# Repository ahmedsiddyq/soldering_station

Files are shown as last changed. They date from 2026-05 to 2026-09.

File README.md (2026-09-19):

# Soldering Station
WhatsApp Image 2026-09-19 at 11 39 38 PM
WhatsApp Image 2026-09-19 at 11 39 35 PM

DIY electronic soldering station project containing the hardware design, firmware, simulation files, and mechanical/laser-cut CAD files.

## Project Overview

This repository contains multiple development versions of a temperature-controlled soldering station:

- **LCD / digital soldering station** — PIC-based controller with temperature sensing, set-temperature input, PWM heater control, PI/PID-style control, UART, I²C, and display support.
- **Analog version** — earlier/full analog control design and PCB.
- **CAD / laser-cut parts** — enclosure and mechanical parts used for the station.
- **Simulation files** — Proteus project files for development and testing.

## Repository Structure

```text
soldering_station/
├── Full_anlog_uc38/
│   ├── circut/        # KiCad PCB/schematic
│   └── layout/        # Proteus/simulation and related files
├── lcd_ST/
│   ├── circut/        # KiCad schematic and PCB
│   └── firmware/
│       └── st_16f15223_irsegmet.X/
│           ├── main.c
│           ├── adc.c / adc.h
│           ├── display.c / display.h
│           ├── i2c1.c / i2c1.h
│           ├── pid.c / pid.h
│           ├── pwm.c / pwm.h
│           ├── timer_1ms.c / timer_1ms.h
│           ├── uart.c / uart.h
│           └── pin_deffiine.h
└── laser_cut_cad/
    └── *.lbrn2       # LightBurn CAD files
```

## LCD Soldering Station Firmware

The current firmware is written in C for a Microchip PIC16F1-series MCU and is developed with **MPLAB X / XC8**.

### Main firmware features

- 32 MHz internal oscillator
- Temperature ADC measurement
- Set-temperature ADC input
- 50-sample moving average
- 200 ms temperature-control period
- PWM heater control
- PI/PID-style temperature control
- Integral anti-windup
- 1 ms timer scheduling
- UART at 9600 baud
- I²C interface
- Numeric display
- Automatic display of the set temperature after a significant setpoint change

The main control loop collects ADC temperature samples into a 50-element buffer and calculates the average before updating the heater duty cycle.

### Current control parameters

```c
#define AVG_SAMPLES       50
#define PID_PERIOD_MS     200

#define S  20
#define KI 1
#define KP 5
```

PWM duty is limited to:

```text
0 ... 1000
```

## Pin Assignment

The current firmware pin map is documented in `pin_deffiine.h`.

| MCU Pin | Function |
|---|---|
| RA5 | Temperature ADC |
| RA4 | Temperature-set ADC |
| RC5 | Current sensing |
| RC4 | Heater PWM gate |
| RC2 | I²C SCL |
| RC1 | I²C SDA |
| RC0 | UART TX |
| RA2 | UART RX |
| RA1 | ICSPDAT |
| RA0 | ICSPCLK |

> Verify the exact MCU part number against the schematic and datasheet before building. Some existing firmware comments/configuration reference different PIC16F1522x/15225 variants.

## Firmware Build

Open:

```text
lcd_ST/firmware/st_16f15223_irsegmet.X
```

Development environment:

- MPLAB X IDE
- XC8 compiler
- PIC16F1522x device support package
- PICkit/programmer compatible with the selected MCU

The project contains the MPLAB X `nbproject` configuration and source files.

## Hardware Design

### LCD version

Located under:

```text
lcd_ST/circut/lcd_soldring_staion/
```

Main files:

- `lcd_soldring_staion.kicad_sch`
- `lcd_soldring_staion.kicad_pcb`

### Analog version

Located under:

```text
Full_anlog_uc38/circut/solder_staion/
```

Main files:

- `solder_staion.kicad_sch`
- `solder_staion.kicad_pcb`

## Simulation

Proteus simulation/development files are located in:

```text
Full_anlog_uc38/layout/
```

## Mechanical / Laser-Cut Design

Laser-cut enclosure/mechanical files are located in:

```text
laser_cut_cad/
```

The `.lbrn2` files can be opened with **LightBurn**.

## Development Status

This is an active DIY electronics project. Hardware, firmware, control parameters, and mechanical designs are still being developed and revised.

Current development includes:

- Temperature-control stability
- PI/PID tuning
- Temperature filtering
- Current sensing
- LCD/display interface
- PCB and enclosure development

## Safety

A soldering station contains a high-temperature heating element and may contain hazardous mains voltages depending on the power-supply design.

Use appropriate electrical isolation, fusing, grounding, thermal protection, over-temperature protection, enclosure, and strain relief.

Do not operate the heater unattended.

## License

No license has currently been specified for this repository. Unless a license is added, normal copyright restrictions apply to the repository contents.

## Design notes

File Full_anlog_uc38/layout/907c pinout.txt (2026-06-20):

1 heater
2 heater 
3 ground
4 +thermo
5 -thermo

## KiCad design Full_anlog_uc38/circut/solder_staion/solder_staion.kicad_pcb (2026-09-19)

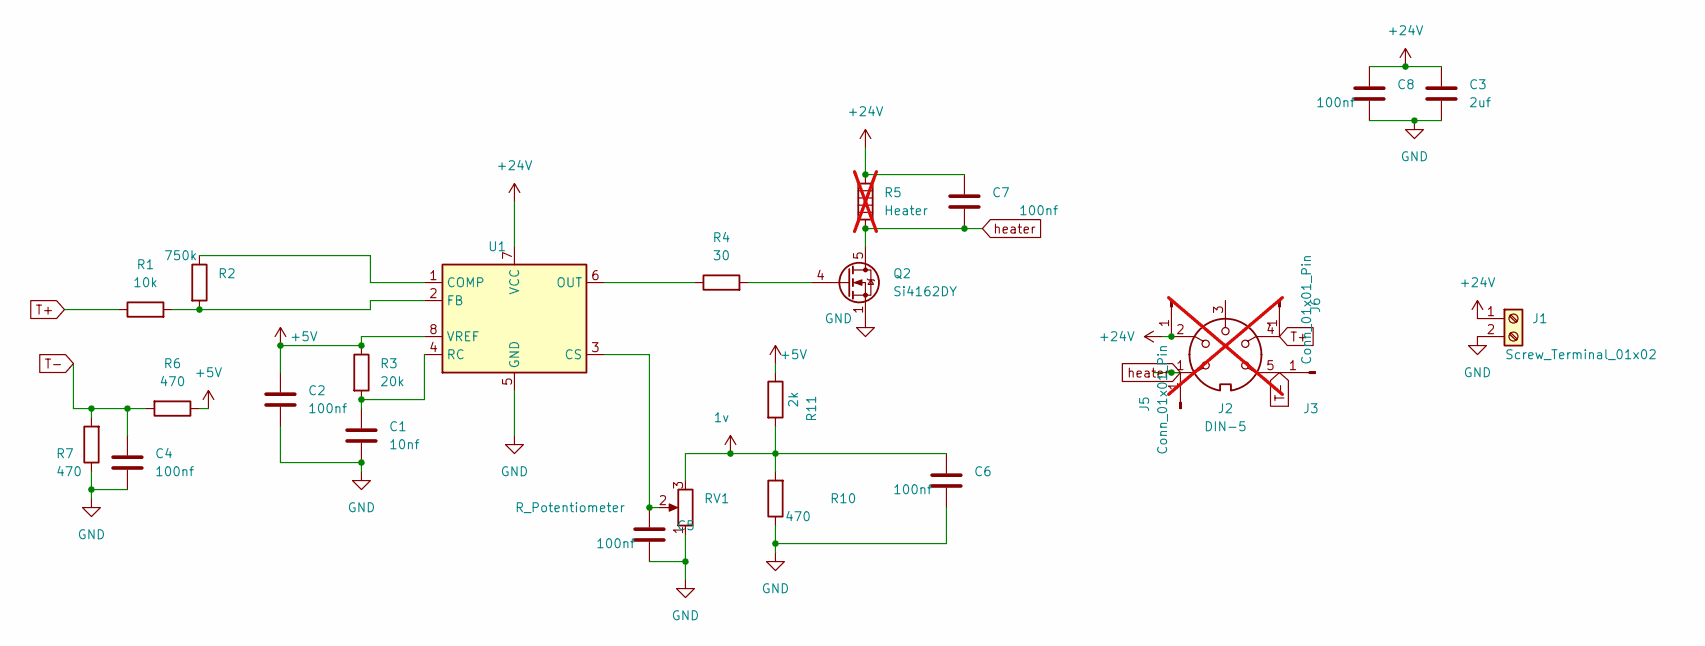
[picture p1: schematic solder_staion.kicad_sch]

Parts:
C1: 10nf; C_1206_3216Metric_Pad1.33x1.80mm_HandSolder
C2, C4, C5, C6, C7, C8: 100nf; C_1206_3216Metric_Pad1.33x1.80mm_HandSolder
C3: 2uf; C_1206_3216Metric_Pad1.33x1.80mm_HandSolder
J1: Screw_Terminal_01x02; TerminalBlock_MaiXu_MX126-5.0-02P_1x02_P5.00mm
J2: DIN-5; not fitted
J3: Conn_01x01_Pin; JST_XH_B1B-XH-AM_1x01_P2.50mm_Vertical
J4, J5, J6: Conn_01x01_Pin; PinHeader_1x01_P2.54mm_Horizontal
Q2: Si4162DY; SOIC-8_3.9x4.9mm_P1.27mm
R1: 10k; R_1206_3216Metric_Pad1.30x1.75mm_HandSolder
R2: 750k; R_1206_3216Metric_Pad1.30x1.75mm_HandSolder
R3: 20k; R_1206_3216Metric_Pad1.30x1.75mm_HandSolder
R4: 30; R_1206_3216Metric_Pad1.30x1.75mm_HandSolder
R5: Heater; not fitted
R6, R7, R10: 470; R_1206_3216Metric_Pad1.30x1.75mm_HandSolder
R11: 2k; R_1206_3216Metric_Pad1.30x1.75mm_HandSolder
RV1: R_Potentiometer; Potentiometer_ACP_CA9-H3,8_Horizontal
U1: UC3842_SOIC8; SOIC-8_3.9x4.9mm_P1.27mm

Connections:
1v: C6.1, R10.2, R11.2, RV1.3
+5V: C2.1, R3.1, R6.1, R11.1, U1.8 (VREF)
+24V: C3.1, C7.1, C8.1, J1.1, J2.2, J4.1, R5.1, U1.7 (VCC)
GND: C1.2, C2.2, C3.2, C4.2, C5.2, C6.2, C8.2, J1.2, Q2.1 (S), Q2.2 (S), Q2.3 (S), R7.1, R10.1, RV1.1, U1.5 (GND)
unnamed: Q2.4 (G), R4.2
unnamed: R2.1, U1.1 (COMP)
unnamed: C5.1, RV1.2, U1.3 (CS)
unnamed: R1.2, R2.2, U1.2 (FB)
unnamed: R4.1, U1.6 (OUT)
unnamed: C1.1, R3.2, U1.4 (RC)
T+: J2.4, J6.1, R1.1
T-: C4.1, J2.5, J3.1, R6.2, R7.2
heater: C7.2, J2.1, J5.1, Q2.5 (D), Q2.6 (D), Q2.7 (D), Q2.8 (D), R5.2

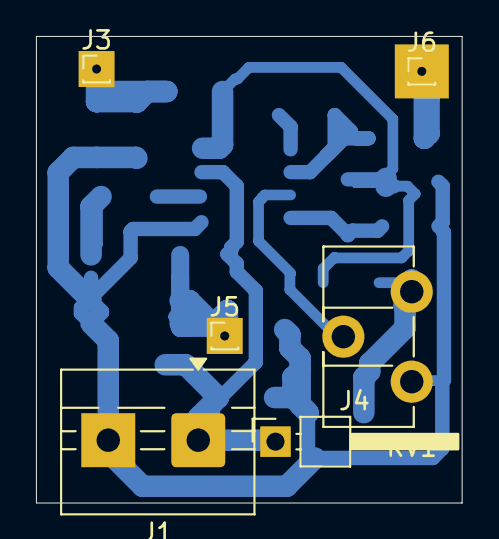
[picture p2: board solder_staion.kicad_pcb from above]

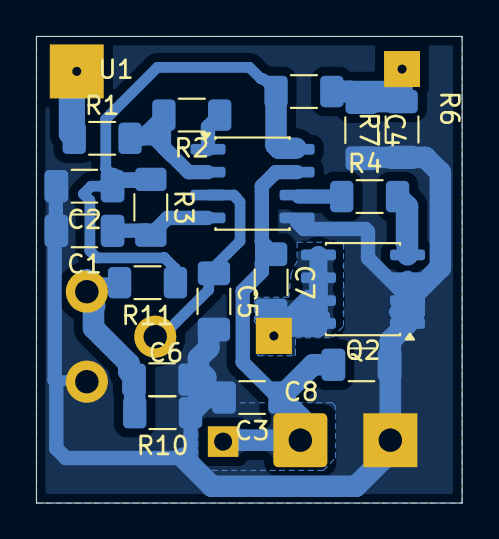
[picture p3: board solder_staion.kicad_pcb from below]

Board: 2 copper layers, 23.6 x 25.9 mm, 24 parts (18 on the bottom side), 13 nets.

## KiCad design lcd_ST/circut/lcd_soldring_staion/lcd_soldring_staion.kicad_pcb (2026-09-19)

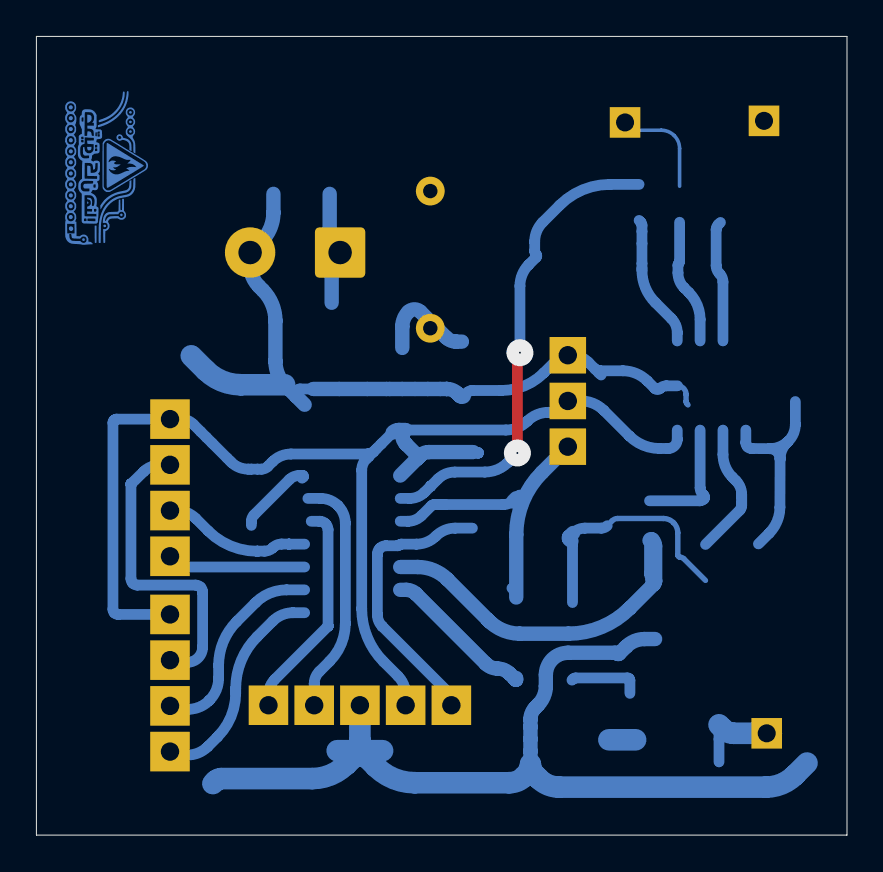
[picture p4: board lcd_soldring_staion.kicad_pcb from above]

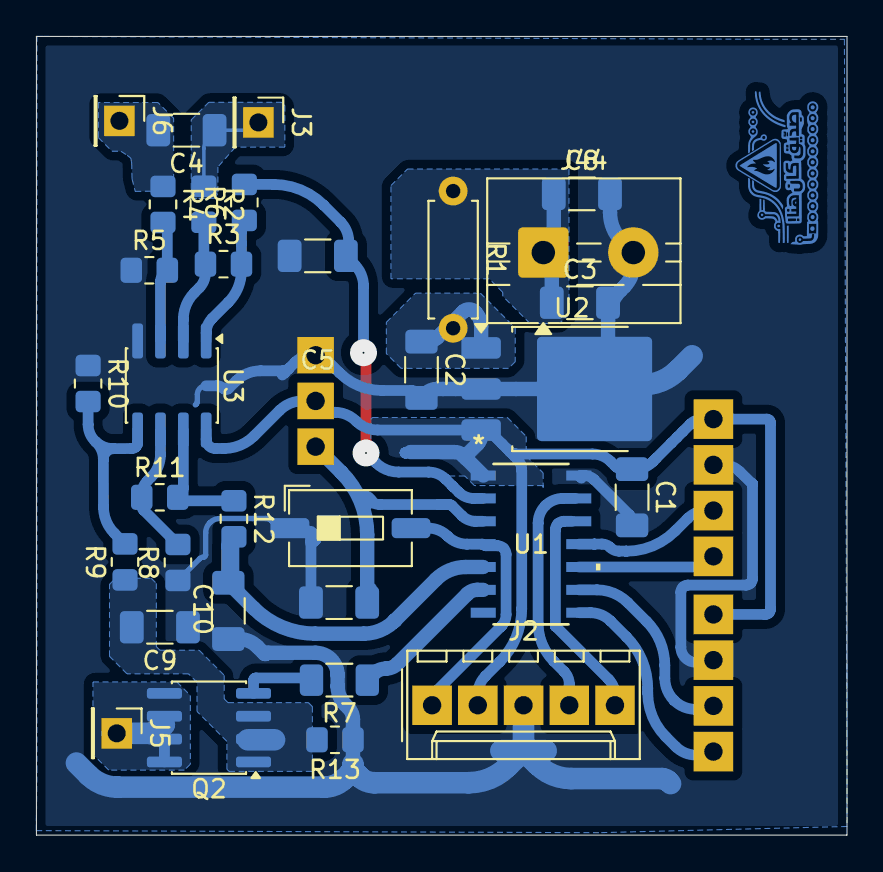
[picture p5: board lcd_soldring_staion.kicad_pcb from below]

Board: 2 copper layers, 45.0 x 44.4 mm, 35 parts (33 on the bottom side), 26 nets.

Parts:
C1: C; C_1206_3216Metric_Pad1.33x1.80mm_HandSolder
C2, C3: 2uf; C_1206_3216Metric_Pad1.33x1.80mm_HandSolder
C4, C5, C6, C8, C9, C10: 100nf; C_1206_3216Metric_Pad1.33x1.80mm_HandSolder
J2: Conn_01x05_Pin; Molex_KK-254_AE-6410-05A_1x05_P2.54mm_Vertical
J3, J5, J6: Conn_01x01_Pin; PinHeader_1x01_P2.54mm_Vertical
J7, J8: Conn_01x04_Pin; 01x04_fat_pins
J10: Conn_01x03_Pin; FanPinHeader_1x03_P2.54mm_Vertical
J44: Screw_Terminal_01x02; TerminalBlock_MaiXu_MX126-5.0-02P_1x02_P5.00mm
Q2: Si4162DY; SOIC-8_3.9x4.9mm_P1.27mm
R1: 50; R_Axial_DIN0207_L6.3mm_D2.5mm_P7.62mm_Horizontal
R2, R4, R6, R8, R9, R12, R13: 1K; R_0805_2012Metric_Pad1.20x1.40mm_HandSolder
R3, R5, R10, R11: 120K; R_0805_2012Metric_Pad1.20x1.40mm_HandSolder
R7: 0.02; R_1206_3216Metric_Pad1.30x1.75mm_HandSolder
SW1: SW_Push; SW_DIP_SPSTx01_Slide_6.7x4.1mm_W6.73mm_P2.54mm_LowProfile_J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
U1: PIC16F15223T-I/SL; SOIC14_SL_MCH
U2: L7805; TO-252-3_TabPin2
U3: LM358; SOIC-8_3.9x4.9mm_P1.27mm

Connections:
+24V: C3.1, C8.1, J44.1, R1.1
A: J2.4, U1.13 (RA0/ICSPDAT)
B: J2.5, U1.12 (RA1/ICSPCLK)
ClC: C6.1, J10.1, U1.3 (RA4)
unnamed: Q2.4 (G), R7.2
unnamed: R3.2, R6.1, U3.1
unnamed: R11.2, R12.1, U3.7
unnamed: C2.1, R1.2, U2.1 (IN)
unnamed: R4.2, R5.2, U3.3 (+)
unnamed: R2.2, R3.1, U3.2 (-)
unnamed: R9.2, R10.2, U3.5 (+)
unnamed: R8.2, R11.1, U3.6 (-)
RX: J8.1, U1.8 (RC2)
T+: C4.2, J6.1, R4.1
T-: C4.1, J3.1, R2.1
TEMP: C5.1, R6.2, U1.2 (RA5)
TX: J8.2, U1.9 (RC1)
VCC: C1.1, J2.2, J7.1, J8.4, J10.2, U1.1 (VDD), U2.3 (OUT), U3.8 (V+)
VPP: J2.1, SW1.2, U1.4 (*MCLR/VPP/RA3)
c+: C9.2, Q2.1 (S), Q2.2 (S), Q2.3 (S), R9.1, R13.2
c-: C1.2, C2.2, C3.2, C5.2, C6.2, C8.2, C9.1, C10.2, J2.3, J7.2, J8.3, J10.3, J44.2, R5.1, R8.1, R10.1, R13.1, SW1.1, U1.14 (VSS), U2.2 (GND), U3.4 (V-)
clk: J7.4, U1.10 (RC0)
current: C10.1, R12.2, U1.5 (RC5)
dat: J7.3, U1.11 (RA2)
heater: J5.1, Q2.5 (D), Q2.6 (D), Q2.7 (D), Q2.8 (D)
heater_gate: R7.1, U1.6 (RC4)

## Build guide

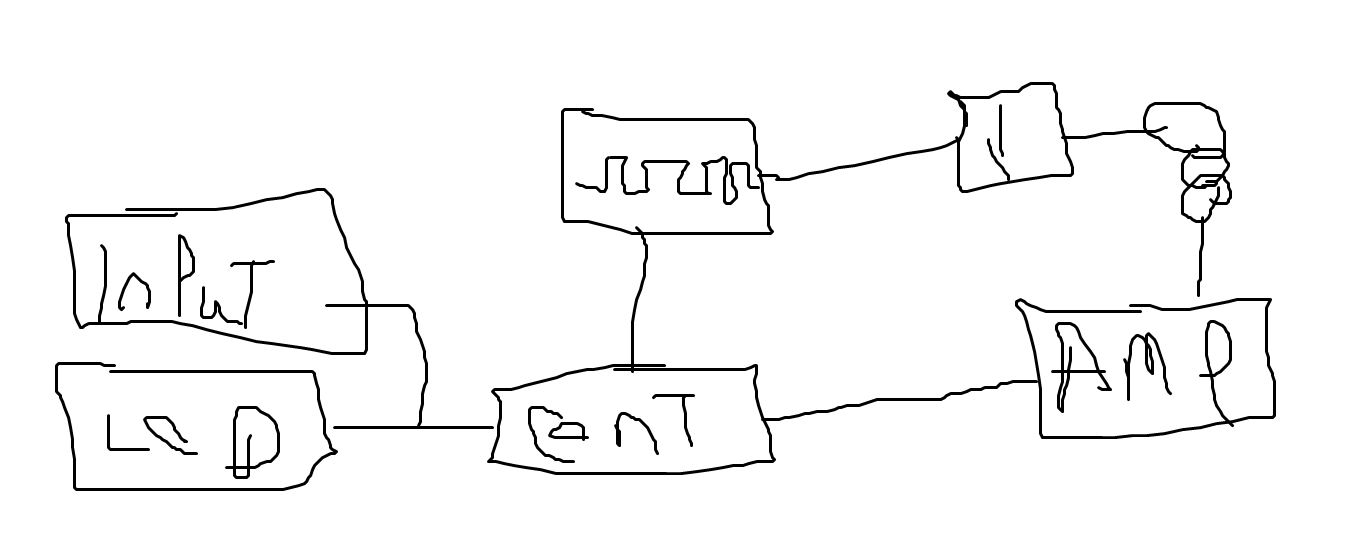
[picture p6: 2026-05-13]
Full_anlog_uc38/layout/Solder_iron_lcd.png

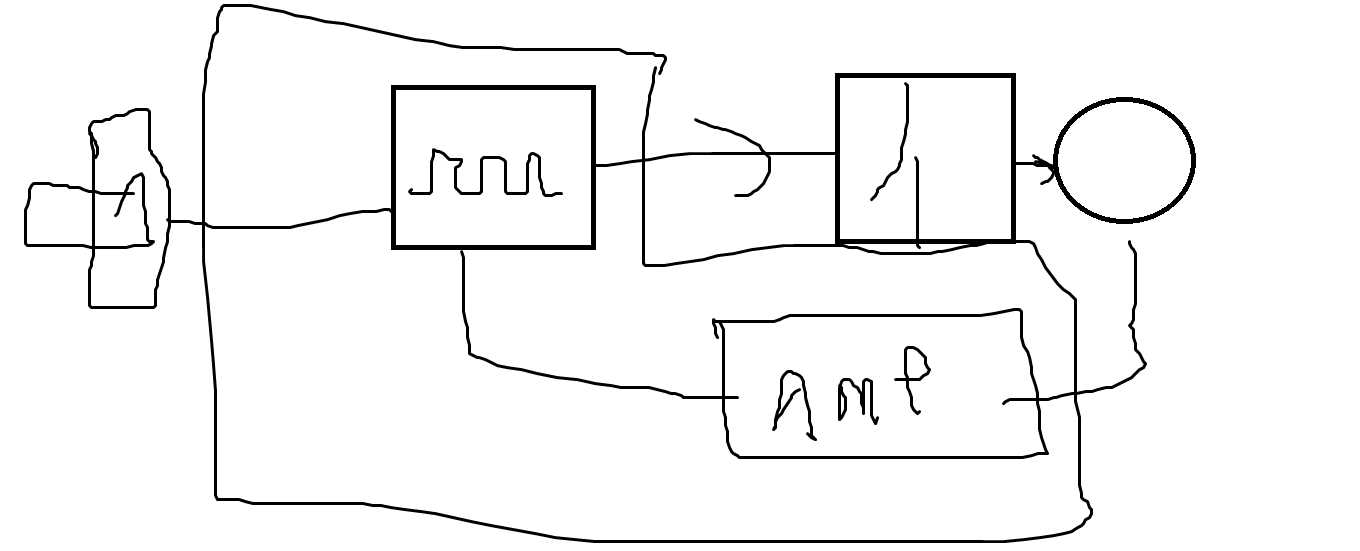
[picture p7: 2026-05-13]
Full_anlog_uc38/layout/solder_staion.png

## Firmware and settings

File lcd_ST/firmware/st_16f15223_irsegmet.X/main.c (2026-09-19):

#include <stdint.h>
#include "header.h"

#define _XTAL_FREQ 32000000UL

#define AVG_SAMPLES       50
#define PID_PERIOD_MS     200
#define SET_DISPLAY_MS    3000


/* ================= GLOBAL VARIABLES ================= */

uint16_t avr_t[AVG_SAMPLES] = {0};

volatile uint8_t tick_1ms = 0;

uint16_t tick_1s = 0;
uint16_t tick_pid = 0;

uint8_t pid_en = 0;
uint8_t SW_Dp = 0;

uint16_t temp_avg = 0;
uint8_t ADC_Read_i = 0;


/* ================= MAIN ================= */

void main(void)
{
    /* ---------- Initialization ---------- */

    pins();

    UART_Init(9600);

    ADC_Init();

    Timer0_1ms_Init();

    PWM_Init();

    I2C1_Init();

    display_init();

    display_set_brightness(1);


    /* ---------- Variables ---------- */

    uint16_t srt_temp =
        (uint16_t)((set_temp * 351UL) / 553UL);

    uint16_t oldsrt_temp = srt_temp;

    int32_t dtt = 0;


    /* ================= MAIN LOOP ================= */

    while (1)
    {

        /* ==========================================
           Calculate set temperature
           ========================================== */

        srt_temp =
            (uint16_t)((set_temp * 351UL) / 553UL);


        /* ==========================================
           PID / Temperature processing
           ========================================== */

        if (pid_en)
        {
            uint32_t sum = 0;


            /* ---------- Calculate 50-sample sum ---------- */

            for (uint8_t p = 0; p < AVG_SAMPLES; p++)
            {
                sum += avr_t[p];
            }


            /* ---------- Calculate average ---------- */

            temp_avg =
                (uint16_t)(sum / AVG_SAMPLES);


            /* ---------- Temperature control ---------- */

            tempSit(temp_avg);


            /* PID request handled */

            pid_en = 0;


            /* ---------- Convert ADC average to temperature ---------- */

            uint16_t temp_avg_c =
                (uint16_t)((temp_avg * 351UL) / 553UL);


            /* ---------- Display ---------- */

            if (!SW_Dp)
            {
                /* Display measured temperature */

                display_write_number(temp_avg_c);
            }
            else
            {
                /* Display set temperature */

                display_write_number(srt_temp);
            }
        }


        /* ==========================================
           1 ms timer event
           ========================================== */

        if (tick_1ms)
        {
            tick_1ms = 0;


            /* ======================================
               Read ADC and store sample
               ====================================== */

            avr_t[ADC_Read_i] =
                ADC_Read(ADC_CH_TEMP);


            ADC_Read_i++;


            /* Circular buffer */

            if (ADC_Read_i >= AVG_SAMPLES)
            {
                ADC_Read_i = 0;
            }


            /* ======================================
               PID timing
               ====================================== */

            tick_pid++;


            if (tick_pid >= PID_PERIOD_MS)
            {
                tick_pid = 0;

                pid_en = 1;
            }


            /* ======================================
               Set-temperature display timer
               ====================================== */

            if (SW_Dp)
            {
                tick_1s++;


                if (tick_1s >= SET_DISPLAY_MS)
                {
                    tick_1s = 0;

                    SW_Dp = 0;
                }
            }


            /* ======================================
               Detect set-temperature change
               ====================================== */

            dtt =
                (int32_t)srt_temp -
                (int32_t)oldsrt_temp;


            /* Absolute value */

            if (dtt < 0)
            {
                dtt = -dtt;
            }


            /* ======================================
               Set temperature changed significantly
               ====================================== */

            if (dtt > 20)
            {
                oldsrt_temp = srt_temp;

                SW_Dp = 1;

                tick_1s = 0;
            }
        }
    }
}

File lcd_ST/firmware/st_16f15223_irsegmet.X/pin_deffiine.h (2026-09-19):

// PIC16F15223T-I/SL pin map (from schematic)
//
// RA5 (pin 2)  = TEMP
// RA4 (pin 3)  = temp_set
// RA3 (pin 4)  = MCLR/VPP
// RC5 (pin 5)  = current
// RC4 (pin 6)  = heater_gate
// RC3 (pin 7)  = not connected
// RC2 (pin 8)  = clk  -> I2C SCL
// RC1 (pin 9)  = dat  -> I2C SDA
// RC0 (pin 10) = TX
// RA2 (pin 11) = RX
// RA1 / RA0    = ICSPCLK / ICSPDAT (leave alone)

#define I2C1_SCL_TRIS   TRISCbits.TRISC2
#define I2C1_SDA_TRIS   TRISCbits.TRISC1
#define I2C1_SCL_ANSEL  ANSELCbits.ANSC2
#define I2C1_SDA_ANSEL  ANSELCbits.ANSC1


void pins(void)
{
    // =========================
    // GPIO direction
    // =========================
    TRISAbits.TRISA5 = 1;   // TEMP        = RA5, input
    TRISAbits.TRISA4 = 1;   // temp_set    = RA4, input

    TRISCbits.TRISC4 = 0;   // heater_gate = RC4, output
    TRISCbits.TRISC5 = 1;   // current     = RC5, input

    TRISCbits.TRISC0 = 0;   // TX          = RC0, output
    TRISAbits.TRISA2 = 1;   // RX          = RA2, input

    // RC3 is unconnected: drive it low as an output so it doesn't float
    LATCbits.LATC3   = 0;
    TRISCbits.TRISC3 = 0;


    // =========================
    // Analog / Digital
    // =========================
 
    ANSELAbits.ANSA5 = 1;   // TEMP
    ANSELAbits.ANSA4 = 1;   // temp_set
    ANSELAbits.ANSA2 = 0;   // RX

    ANSELCbits.ANSC5 = 1;   // current
    ANSELCbits.ANSC4 = 0;   // heater_gate
    ANSELCbits.ANSC3 = 0;   // unused
    ANSELCbits.ANSC0 = 0;   // TX
    I2C1_SCL_ANSEL   = 0;   // RC2 (SCL)
    I2C1_SDA_ANSEL   = 0;   // RC1 (SDA)


    // =========================
    // Unlock PPS
    // =========================

    PPSLOCK = 0x55;
    PPSLOCK = 0xAA;
    PPSLOCKbits.PPSLOCKED = 0;


    // =========================
    // UART1
    // =========================

    // TX1 -> RC0
    RC0PPS = 0x05;

    // RX1 <- RA2
    RXPPS = 0x02;
    
    
// PWM3 -> RC4 (heater_gate)
RC4PPS = 0x03;      // PWM3

    // =========================
    // I2C1
    // =========================

    // Both pins stay inputs; the MSSP drives them open-drain as needed
    I2C1_SCL_TRIS = 1;
    I2C1_SDA_TRIS = 1;

    // I2C inputs
    SSP1CLKPPS = 0x12;      // RC2 -> SCL1 input
    SSP1DATPPS = 0x11;      // RC1 -> SDA1 input

    // I2C outputs (must be on the same pins as the inputs)
    RC2PPS = 0x07;          // SCL1 -> RC2
    RC1PPS = 0x08;          // SDA1 -> RC1

    // Weak pull-ups (verify RC2I2C / RC1I2C exist on this device;
    // otherwise use WPUC, and prefer external resistors for real I2C)
WPUCbits.WPUC2 = 1;     // SCL (RC2)
WPUCbits.WPUC1 = 1;     // SDA (RC1)
    // =========================
    // Lock PPS
    // =========================

    PPSLOCK = 0x55;
    PPSLOCK = 0xAA;
    PPSLOCKbits.PPSLOCKED = 1;
}

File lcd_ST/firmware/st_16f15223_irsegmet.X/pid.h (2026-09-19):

#ifndef PID_H
#define PID_H
#include <xc.h>
#include <stdint.h>
#include "adc.h"
#include "pwm.h"
int32_t i_PID = 0;
#define S  20
#define KI 1
#define KP 5
#define temp     ADC_Read(ADC_CH_TEMP)
#define CURRENT  ADC_Read(ADC_CH_CURRENT)
#define set_temp ADC_Read(ADC_CH_TEMP_SET)
 
void tempSit(uint16_t tempNa);
#endif

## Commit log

2026-06-20 final v1
    [solder_staion.kicad_pcb, solder_staion.kicad_sch]
2026-08-21 new start
    [solder_staion.kicad_pcb, solder_staion.kicad_sch]
2026-08-29 done v0
    [lcd_soldring_staion.kicad_pcb, lcd_soldring_staion.kicad_sch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]
2026-08-29 سوفت وير تايم
2026-09-04 V2_PCB EDITING
    [lcd_soldring_staion.kicad_pcb, lcd_soldring_staion.kicad_sch]
2026-09-04 pcb v2
    [lcd_soldring_staion.kicad_pcb, lcd_soldring_staion.kicad_sch]
2026-09-11 i2c work
